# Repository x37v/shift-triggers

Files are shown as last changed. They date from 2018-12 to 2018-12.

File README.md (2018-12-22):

# shift-triggers

This is a kicad pcb/schematic project for driving modular synthesizer triggers with a few pins on a microcontroller using a shift register.

It provides 16 trigger outputs, an optional 3v->5v set of inputs, and the ability to cascade several boards.

It uses an MTA style connector for power, and should be able to be driven by 12 or 15v, probably even 9.



## License

<br /><span xmlns:dct="http://purl.org/dc/terms/" property="dct:title">shift-triggers</span> by <a xmlns:cc="http://creativecommons.org/ns#" href="https://github.com/x37v/shift-triggers" property="cc:attributionName" rel="cc:attributionURL">Alex Norman</a> is licensed under a <a rel="license" href="http://creativecommons.org/licenses/by/4.0/">Creative Commons Attribution 4.0 International License</a>.<br />Based on a work at <a xmlns:dct="http://purl.org/dc/terms/" href="https://github.com/pichenettes/eurorack/tree/master/grids/hardware_design" rel="dct:source">https://github.com/pichenettes/eurorack/tree/master/grids/hardware_design</a>.

## Thanks

Thanks to [Mutable Instruments](https://mutable-instruments.net) for providing example schematics.
I modeled these triggers off the [Grids](https://mutable-instruments.net/modules/grids/)
[schematic](https://github.com/pichenettes/eurorack/tree/master/grids/hardware_design).

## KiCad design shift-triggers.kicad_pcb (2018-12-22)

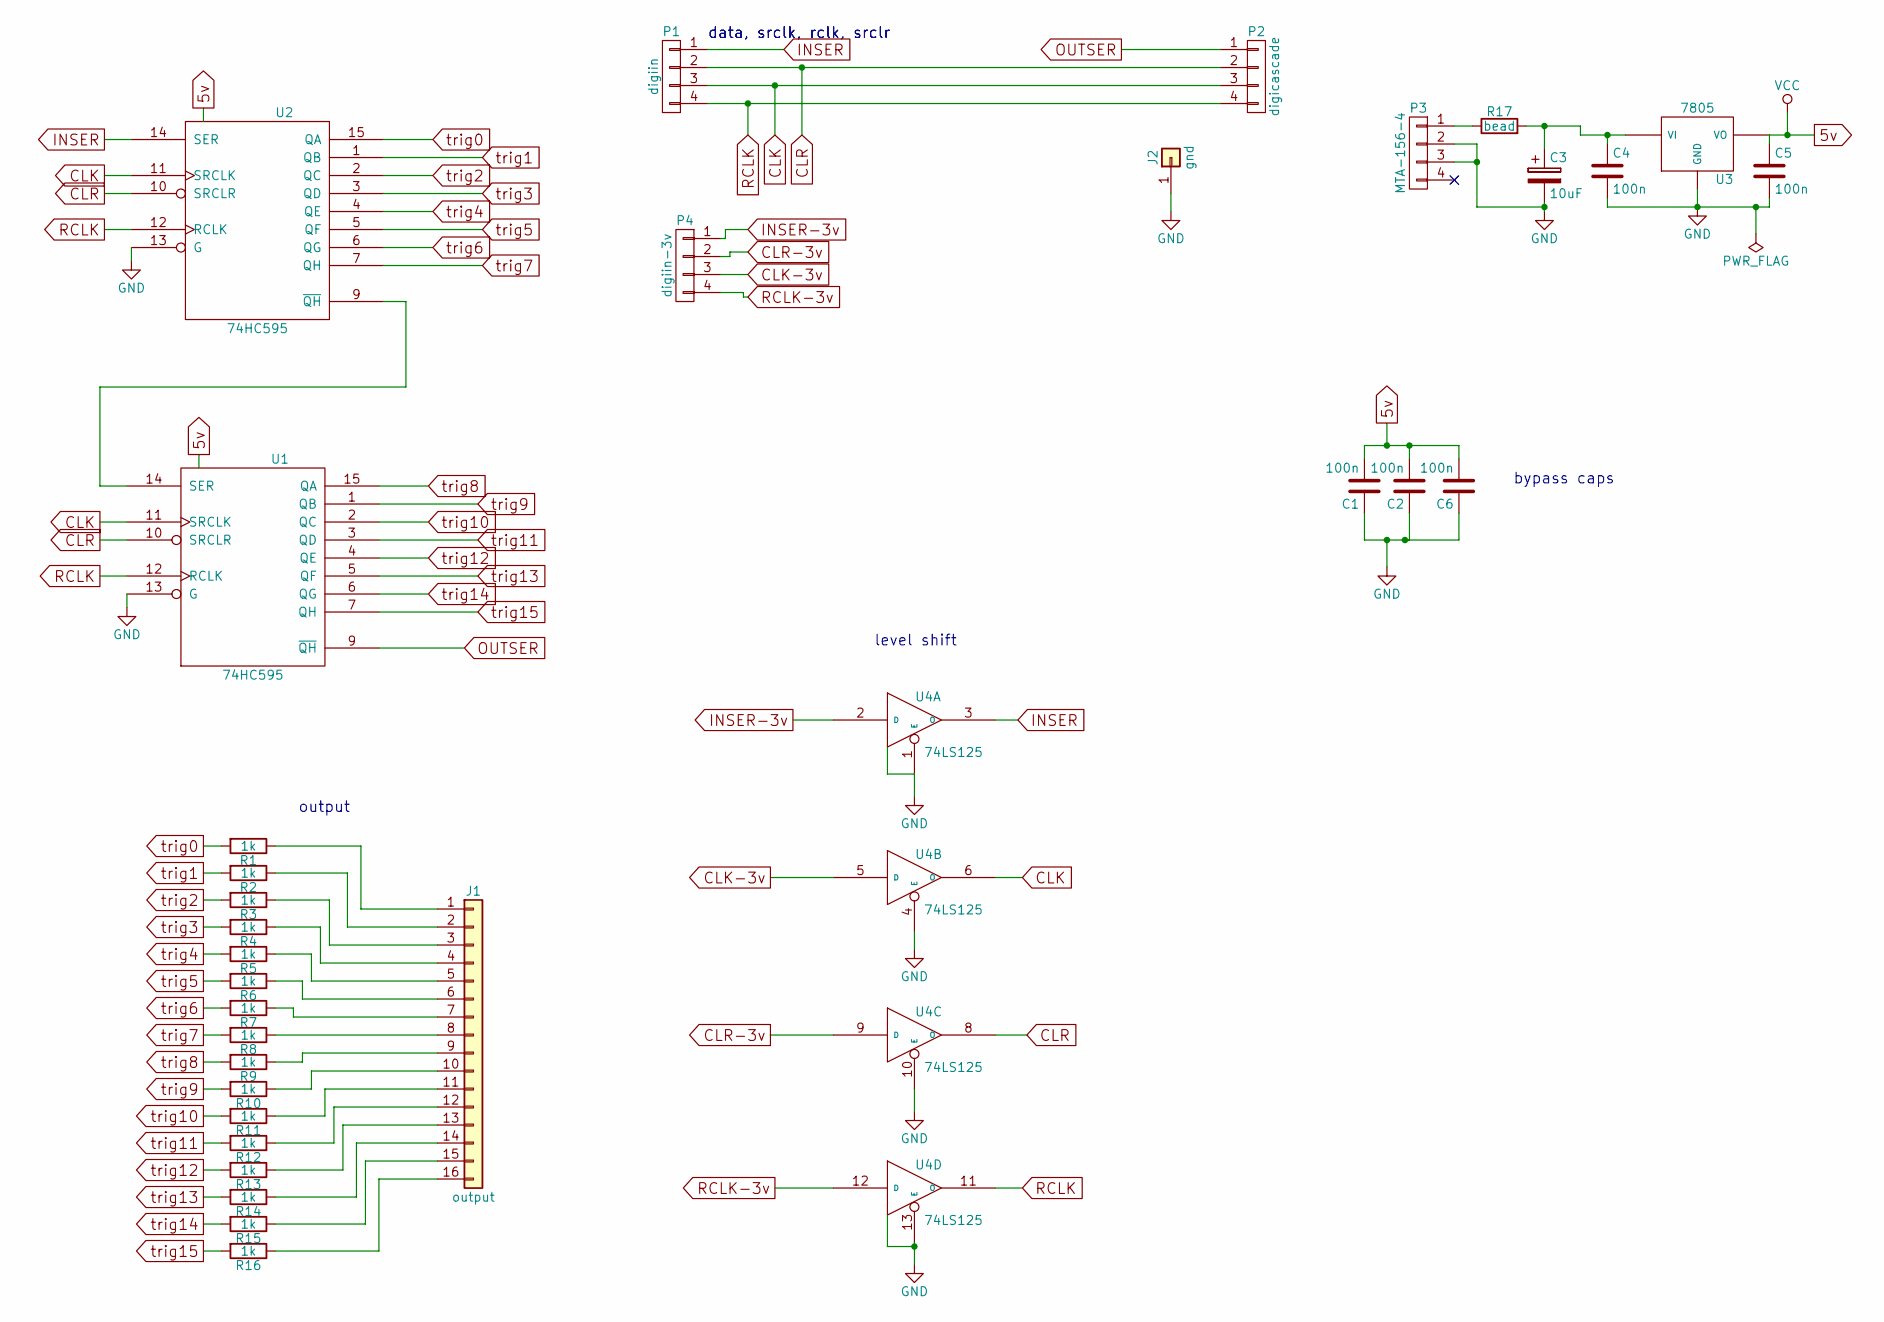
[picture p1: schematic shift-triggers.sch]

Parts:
C1, C2, C6: 100n; C_Disc_D3.4mm_W2.1mm_P2.50mm
C3: 10uF; CP_Radial_D7.5mm_P2.50mm
C4, C5: 100n; C_Disc_D4.3mm_W1.9mm_P5.00mm
J1: output; Pin_Header_Straight_1x16_Pitch2.54mm
J2: gnd; Pin_Header_Straight_1x01_Pitch2.54mm
P1: digiin; Pin_Header_Straight_1x04_Pitch2.54mm
P2: digicascade; Pin_Header_Straight_1x04_Pitch2.54mm
P3: MTA-156-4
P4: digiin-3v; Pin_Header_Straight_1x04_Pitch2.54mm
R1, R2, R3, R4, R5, R6, R7, R8, R9, R10, R11, R12, R13, R14, R15, R16: 1k; R_Axial_DIN0204_L3.6mm_D1.6mm_P7.62mm_Horizontal
R17: bead; R_Axial_DIN0207_L6.3mm_D2.5mm_P10.16mm_Horizontal
U1, U2: 74HC595; DIP-16_W7.62mm_LongPads
U3: 7805; TO-220_Vertical
U4: 74LS125; DIP-14_W7.62mm_LongPads

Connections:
5v: C1.2, C2.2, C5.1, C6.2, U1.16 (VCC), U2.16 (VCC), U3.3 (VO), U4.14 (VCC)
CLK: P1.3, P2.3, U1.11 (SRCLK), U2.11 (SRCLK), U4.6 (O); also elsewhere on the board
CLK-3v: P4.3, U4.5 (D); also elsewhere on the board
CLR: P1.2, P2.2, U1.10 (SRCLR), U2.10 (SRCLR), U4.8 (O); also elsewhere on the board
CLR-3v: P4.2, U4.9 (D); also elsewhere on the board
GND: C1.1, C2.1, C3.2, C4.2, C5.2, C6.1, J2.1, P3.2, P3.3, U1.8 (GND), U1.13 (G), U2.8 (GND), U2.13 (G), U3.2 (GND), U4.1 (E), U4.4 (E), U4.7 (GND), U4.10 (E), U4.13 (E); also elsewhere on the board
INSER: P1.1, U2.14 (SER), U4.3 (O); also elsewhere on the board
INSER-3v: P4.1, U4.2 (D); also elsewhere on the board
unnamed: C3.1, C4.1, R17.2, U3.1 (VI)
unnamed: J1.1, R1.1
unnamed: J1.2, R2.1
unnamed: J1.3, R3.1
unnamed: J1.4, R4.1
unnamed: J1.5, R5.1
unnamed: J1.6, R6.1
unnamed: J1.7, R7.1
unnamed: J1.8, R8.1
unnamed: J1.9, R9.1
unnamed: J1.10, R10.1
unnamed: J1.11, R11.1
unnamed: J1.12, R12.1
unnamed: J1.13, R13.1
unnamed: J1.14, R14.1
unnamed: J1.15, R15.1
unnamed: J1.16, R16.1
unnamed: P3.1, R17.1
unnamed: U1.14 (SER), U2.9 (~QH)
OUTSER: P2.1, U1.9 (~QH)
RCLK: P1.4, P2.4, U1.12 (RCLK), U2.12 (RCLK), U4.11 (O); also elsewhere on the board
RCLK-3v: P4.4, U4.12 (D); also elsewhere on the board
trig0: R1.2, U2.15 (QA)
trig1: R2.2, U2.1 (QB)
trig2: R3.2, U2.2 (QC)
trig3: R4.2, U2.3 (QD)
trig4: R5.2, U2.4 (QE)
trig5: R6.2, U2.5 (QF)
trig6: R7.2, U2.6 (QG)
trig7: R8.2, U2.7 (QH)
trig8: R9.2, U1.15 (QA)
trig9: R10.2, U1.1 (QB)
trig10: R11.2, U1.2 (QC)
trig11: R12.2, U1.3 (QD)
trig12: R13.2, U1.4 (QE)
trig13: R14.2, U1.5 (QF)
trig14: R15.2, U1.6 (QG)
trig15: R16.2, U1.7 (QH)

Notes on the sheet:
data, srclk, rclk, srclr
bypass caps
level shift
output

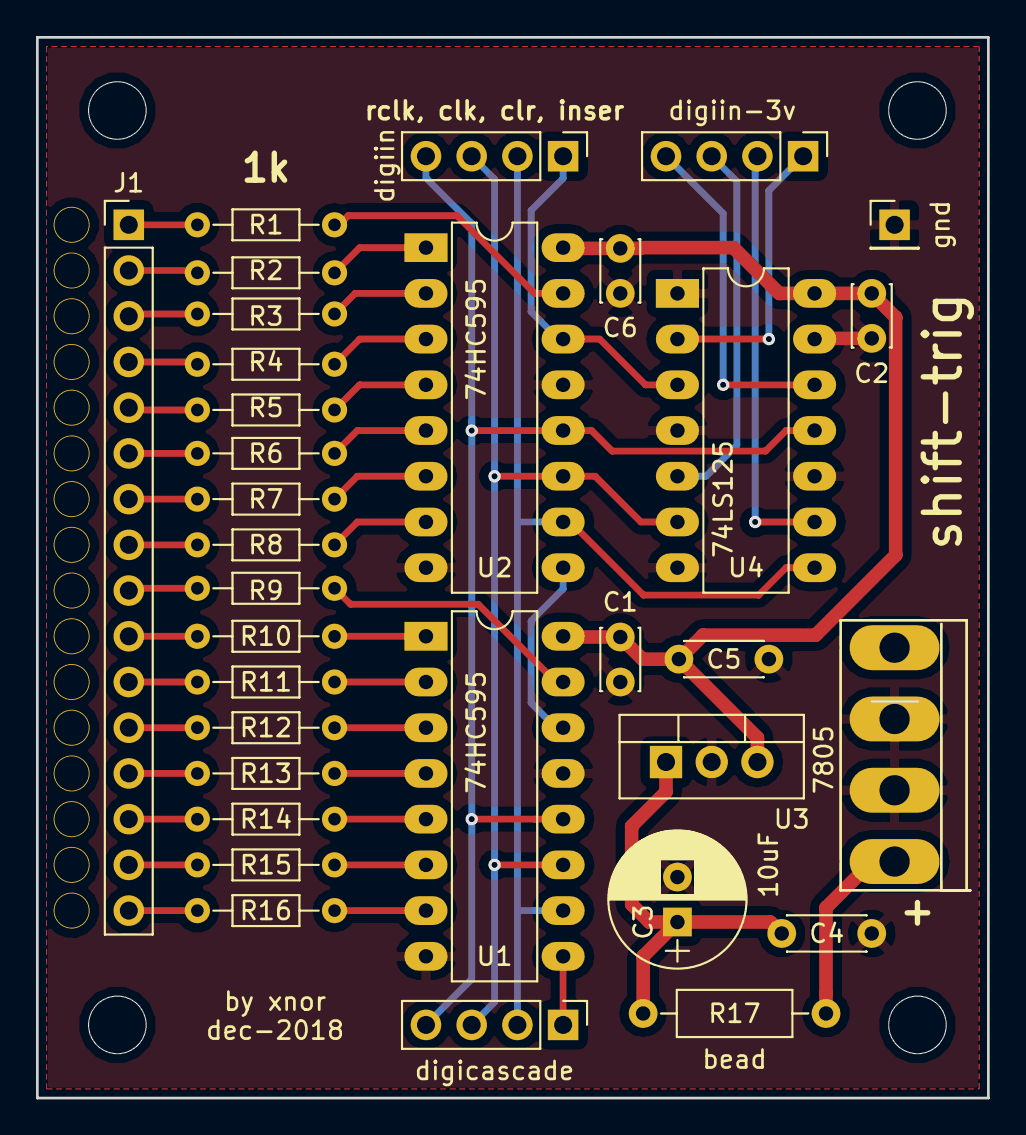
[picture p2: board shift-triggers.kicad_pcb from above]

Board: 2 copper layers, 52.8 x 58.9 mm, 37 parts (0 on the bottom side), 46 nets.

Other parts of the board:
GND: gnd; Pin_Header_Straight_1x01_Pitch2.54mm
IN-3v: digiin-3v; Pin_Header_Straight_1x04_Pitch2.54mm
IN-5v: digiin; Pin_Header_Straight_1x04_Pitch2.54mm
REF1, REF2, REF3, REF4: MountingHole_3.2mm_M3

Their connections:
CLK: IN-5v.3; also elsewhere on the board
CLK-3v: IN-3v.3; also elsewhere on the board
CLR: IN-5v.2; also elsewhere on the board
CLR-3v: IN-3v.2; also elsewhere on the board
GND: GND.1; also elsewhere on the board
INSER: IN-5v.1; also elsewhere on the board
INSER-3v: IN-3v.1; also elsewhere on the board
RCLK: IN-5v.4; also elsewhere on the board
RCLK-3v: IN-3v.4; also elsewhere on the board

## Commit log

2018-12-22 initial schematic and pcb
    [shift-triggers.kicad_pcb, shift-triggers.sch]
2018-12-22 added ground, updated packages
    [shift-triggers.sch]
2018-12-22 more dialed in layout
    [shift-triggers.kicad_pcb]
2018-12-22 mostly layed out now
    [shift-triggers.kicad_pcb, shift-triggers.sch]
2018-12-22 finalized pcb?
    [shift-triggers.kicad_pcb]
